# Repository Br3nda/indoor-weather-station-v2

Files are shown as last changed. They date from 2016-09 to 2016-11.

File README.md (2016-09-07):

# indoor-weather-station-v2
Software for VCW indoor weatherstation

## Licensing

This software is GPL 3.0.

Included is driver software - HTS221 and LPS25 drivers, with their own copyrights
they have been released by their author, Amel Technology, under the LGPL2.1 license

	https://github.com/ameltech/sme-hts221-library
	https://github.com/ameltech/sme-lps25h-library

Our minor changes to these files are also released under LGPL2.1

---------------------------------------------------------------

## Data compression formats:

###humidity/temp compression - humidity is 7 bits 0-100, temp is 8 bits signed C
```
if bit 7 of byte 0 is 1 then bits 6:0 of byte0 is % humidity, byte1 is temp in C
if bit 7 of byte 0 is 0 then bits 6:4 are a signed diff of humidity from previous value, 3:0 are a signed diff of temp from previous value
if bits 7:4 of byte 0 are 1111 it is an escape (see below)
```
 
###pressure compression
```
if bit 0 of byte0 is set bits 6:0 are a signed delta of the pressure in kPa
if bit 1 of byte0 is set bits 6:0 of byte0 is MSB of pressure, byte 1 is LSB of pressure in kPa
if bits 7:4 of byte 0 are 1111 it is an escape (see below)
```

###escapes
```
1111 1111 - end of stream (unwritten FLASH)
1111 0000 - time signature
1111 0001 - time signature + change following samples to temp/humidity only (first following sample will be a full sample)
1111 0010 - time signature + change following samples to pressure only (first following sample will be a full sample)
1111 0011 - time signature + change following samples to temp/humidity followed by pressure (first following sample will be a full sample)
1111 0100 - followed by 2 bytes MSB LSB, sampling rate in seconds (default is 60 seconds, one sample per minute)
1111 0101 - followed by 0 terminated string comment
1111 0110 - followed by a 1-byte value - 'mark' a user inserted mark in the stream (for example "I turned on the heater here")
1111 0111 - null - ignored for padding
1111 1000 - followed by 1-byte count 1-255 - previous value didn't change to N samples
1111 1001 - 1110 undefined
```

###time signature:
```
byte0 - bits 7:0 years since 2000 0-254 - value '0xff' means no time is known (bytes1-4 are missing)
byte1 - bits 7:4 month 1-12,  bits 3:0 day MSB 1-31
byte2 - bit 7 day LSB 1-23, bits 6:2 hour 0-23 bits 1:0 minutes msb
byte3 - bits 7:4 minutes lsb 0-59, bits 3:0 - F means byte4 not included, otherwise undefined, set to 0
byte4 - bits 7:6 undefined set to 0, bits 5:0 seconds
```

---------------------------------------------------------------

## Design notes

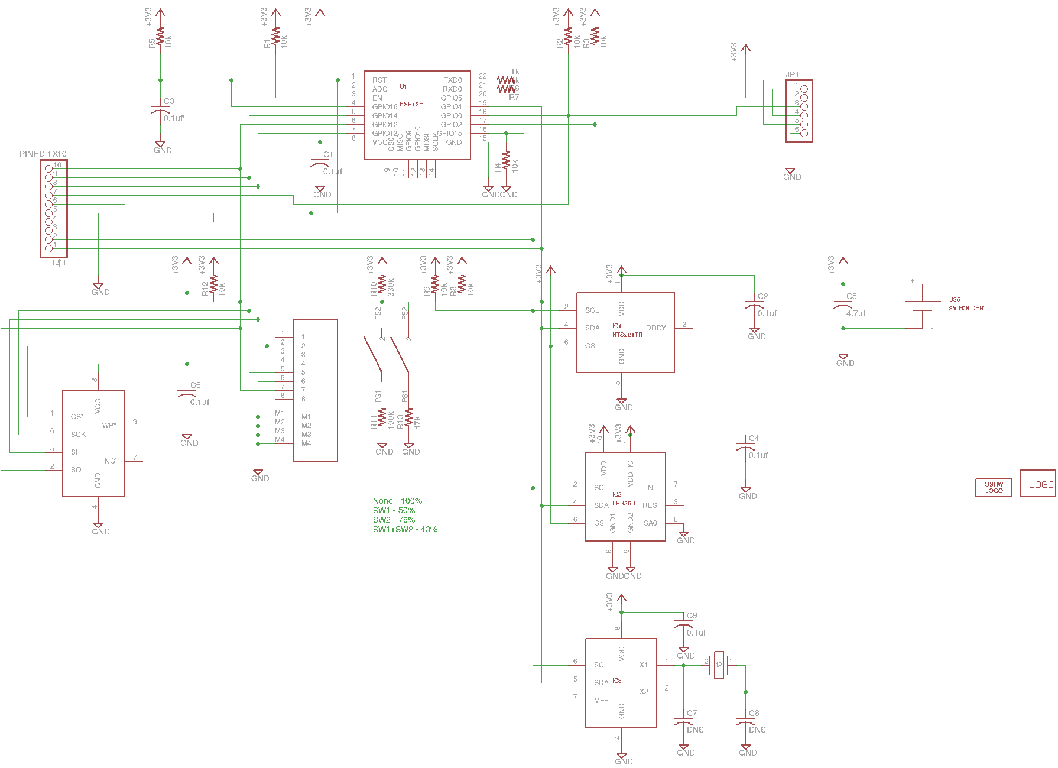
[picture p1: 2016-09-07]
hardware/housesensor.png

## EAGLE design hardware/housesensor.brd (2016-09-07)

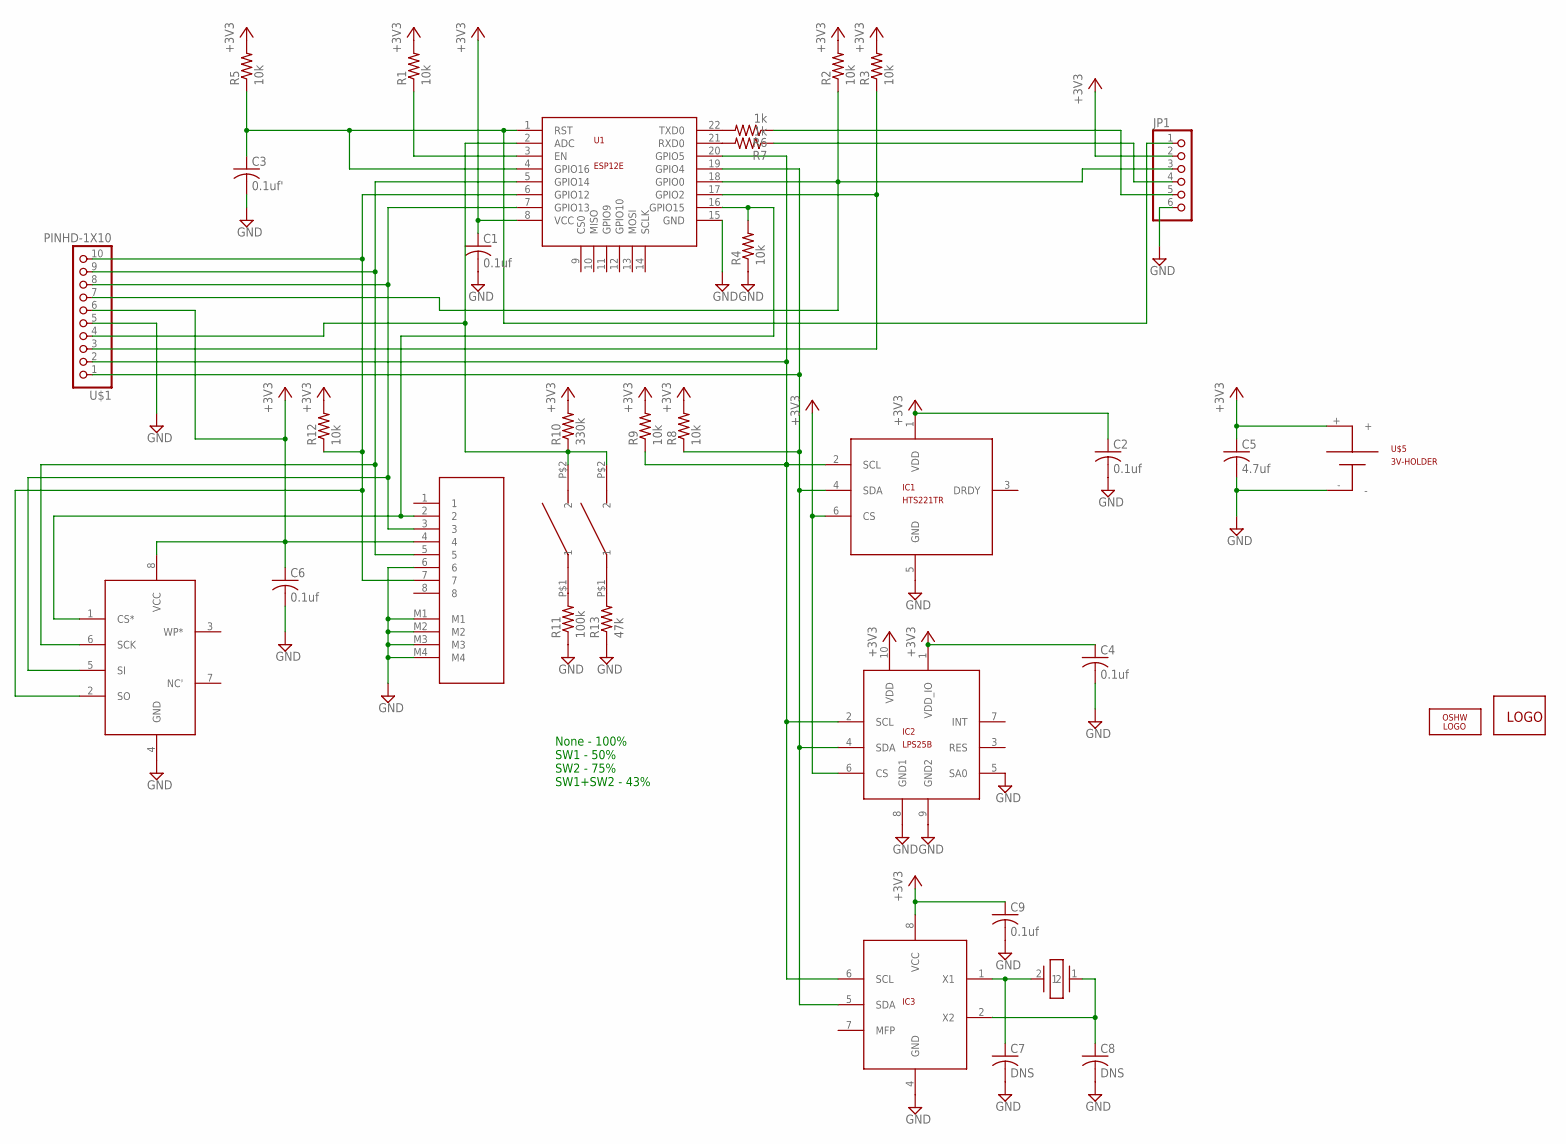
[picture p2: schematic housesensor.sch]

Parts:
C1, C2, C4, C6, C9: 0.1uf; C0603
C3: 0.1uf'; C0603
C5: 4.7uf; C1206
C7, C8: DNS; C0603
IC1: HTS221TR; HTS221
IC2: LPS25B; LPS25
IC3: MCP7940MS08M; SO8M
IC4: SPI-FLASH; SO8J
JP1: PINHD-1X6; 1X06
LOGO1: OSHW_LOGO_FILLX0150-NT; OSHW_FILLX150_NOTEXT
R1, R2, R3, R4, R5, R8, R9, R12: 10k; R0603
R6, R7: 1k; R0603
R10: 330k; R0603
R11: 100k; R0603
R13: 47k; R0603
SW1, SW2: RED-SWITCH; SW2
U1: ESP12E; ESP8266-SMD
U$1: PINHD-1X10; 1X10-BIG
U$4: MICRO-SD-SCHD1A0101; MICROSD-P
U$5: 3V-HOLDER
U$6: MOONBASE-LOGO
X1: 32KHZ

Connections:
+3V3: C1.1, C2.1, C4.1, C5.1, C6.1, C9.1, IC1.1 (VDD), IC1.6 (CS), IC2.1 (VDD_IO), IC2.6 (CS), IC2.10 (VDD), IC3.8 (VCC), IC4.8 (VCC), JP1.2, R1.2, R2.2, R3.2, R5.2, R8.2, R9.2, R10.2, R12.2, U1.8 (VCC), U$1.6, U$4.4, U$5.+
EN: R1.1, U1.3 (EN)
GND: C1.2, C2.2, C3.2, C4.2, C5.2, C6.2, C7.2, C8.2, C9.2, IC1.5 (GND), IC2.5 (SA0), IC2.8 (GND1), IC2.9 (GND2), IC3.4 (GND), IC4.4 (GND), JP1.6, R4.1, R11.1, R13.1, U1.15 (GND), U$1.5, U$4.6, U$4.M1, U$4.M2, U$4.M3, U$4.M4, U$5.-
GPIO0: JP1.3, R2.1, U1.18 (GPIO0), U$1.7
GPIO2: R3.1, U1.17 (GPIO2), U$1.3
GPIO12: IC4.2 (SO), R12.1, U1.6 (GPIO12), U$1.10, U$4.7
GPIO13: IC4.5 (SI), U1.7 (GPIO13), U$1.8, U$4.3
GPIO14: IC4.6 (SCK), U1.5 (GPIO14), U$1.9, U$4.5
GPIO15: IC4.1 (CS*), R4.2, U1.16 (GPIO15), U$4.2
unnamed: R11.2, SW1.P$1 (1)
unnamed: R10.1, SW1.P$2 (2), SW2.P$2 (2), U1.2 (ADC), U$1.4
unnamed: R13.2, SW2.P$1 (1)
unnamed: C8.1, IC3.2 (X2), X1.1
unnamed: C7.1, IC3.1 (X1), X1.2
unnamed: R6.2, U1.22 (TXD0)
unnamed: R7.2, U1.21 (RXD0)
unnamed: JP1.5, R6.1
unnamed: JP1.4, R7.1
RST: C3.1, JP1.1, R5.1, U1.1 (RST), U1.4 (GPIO16)
SCL: IC1.2 (SCL), IC2.2 (SCL), IC3.6 (SCL), R9.1, U1.20 (GPIO5), U$1.2
SDA: IC1.4 (SDA), IC2.4 (SDA), IC3.5 (SDA), R8.1, U1.19 (GPIO4), U$1.1

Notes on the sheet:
None - 100% SW1 - 50% SW2 - 75% SW1+SW2 - 43%

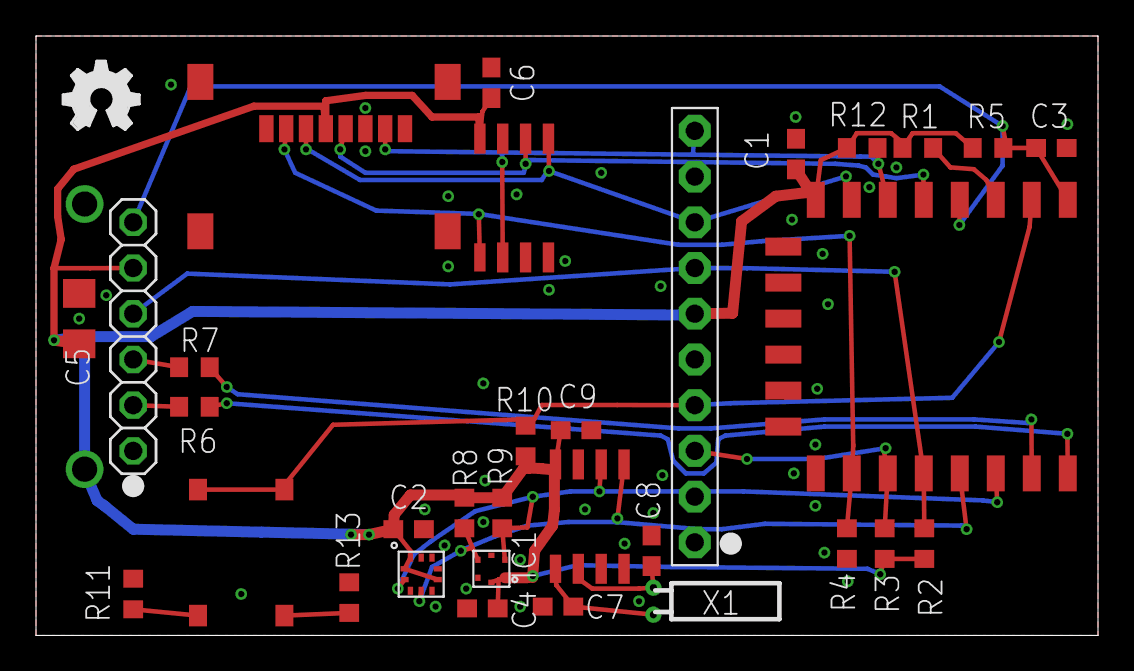
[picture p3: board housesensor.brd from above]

Board: 2 copper layers, 59.0 x 33.3 mm, 36 parts (1 on the bottom side), 21 nets.

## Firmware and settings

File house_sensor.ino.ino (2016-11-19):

/*   
 *   Copyright (C) 2016 Paul Campbell

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
 *   You should have received a copy of the GNU General Public License
 *   along with this program.  If not, see <http://www.gnu.org/licenses/>.
 */

      // humidity/temp compression - humidity is 7 bits 0-100, temp is 8 bits signed C
      // If bit 7 of byte 0 is 1 then bits 6:0 of byte0 is % humidity, byte1 is temp in C
      // if bit 7 of byte 0 is 0 then bits 6:4 are a signed diff of humidity from previous value, 2:0 are a signed diff of temp from previous value, bit 3 
      //      says that a following pressure value is unchanged and omitted
      // if bits 7:4 of byte 0 are 1111 it is an escape (see below)
      // 
      // pressure compression
      // if bit 0 of byte0 is set bits 6:0 are a signed delta of the pressure in kPa
      // if bit 1 of byte0 is set bits 6:0 of byte0 is MSB of pressure, byte 1 is LSB of pressure in kPa
      // if bits 7:4 of byte 0 are 1111 it is an escape (see below)
      //
      // escapes
      //  1111 1111 - end of stream (unwritten FLASH)
      //  1111 0000 - time signature
      //  1111 0001 - time signature + change following samples to temp/humidity only (first following sample will be a full sample)
      //  1111 0010 - time signature + change following samples to pressure only (first Afollowing sample will be a full sample)
      //  1111 0011 - time signature + change following samples to temp/humidity followed by pressure (first following sample will be a full sample)
      //  1111 0100 - followed by 2 bytes MSB LSB, sampling rate in seconds (default is 60 seconds, one sample per minute)
      //  1111 0101 - followed by 0 terminated string comment
      //  1111 0110 - followed by a 1-byte value - 'mark' a user inserted mark in the stream (for example "I turned on the heater here")
      //  1111 0111 - null - ignored for padding
      //  1111 1000 - followed by 1-byte count 1-255 - previous value didn't change to N samples
      //  1111 1001-1110 undefined
      //
      // time signature:
      //  byte0 - bits 7:0 years since 2000 0-254 - value '0xff' means no time is known (bytes1-4 are missing)
      //  byte1 - bits 7:4 month 1-12,  bits 3:0 day MSB 1-31
      //  byte2 - bit 7 day LSB 1-23, bits 6:2 hour 0-23 bits 1:0 minutes msb
      //  byte3 - bits 7:4 minutes lsb 0-59, bits 3:0 - F means byte4 not included, otherwise undefined, set to 0
      //  byte4 - bits 7:6 undefined set to 0, bits 5:0 seconds

#define COUNT 60            // how many samples before trying to push upstream
#define DELAY 1000000       // 1 SEC in uS
#define MAGIC 0x76          // increment this (mod 256) when you make changes to force initialisation
#define FLASH_ERASE 0

extern "C" {
  #include "user_interface.h"
  extern struct rst_info resetInfo; 
  void esp_yield();
}

#include "Wire.h"
#include "HTS221.h"
#include "LPS25H.h"
#include "PC8563.h"
#include "CaptiveConfig.h"
#include "DataUploader.h"
#include "decompress.h"
#include "house_eeprom.h"
#include "Flash.h"



#ifndef cbi
#define cbi(sfr, bit) (_SFR_BYTE(sfr) &= ~_BV(bit))
#endif

#ifndef sbi
#define sbi(sfr, bit) (_SFR_BYTE(sfr) |= _BV(bit))
#endif

#include "pins_arduino.h"
#include "twi.h"


typedef struct rtc_info {
    unsigned char magic;    // MAGIC number
    unsigned char count;    // how many times to wait
    unsigned char state;    
#define STATE_HUMID_PRESENT     0x01    // we have a humididty sensor
#define STATE_PRESSURE_PRESENT  0x02    // we have a pressure sensor
#define STATE_RTC_PRESENT       0x04    // we have an external RTC
#define STATE_SENSORS_ACTIVE    0x08    // take a sample when you wake up
#define STATE_TIME_SET          0x10    // RTC time is valid

    unsigned char   compressor_state;   //
#define CSTATE_SAME       0x01          // we have an active 'same' entry
#define CSTATE_LAST_SAME  0x02          // the last entry we put was deltas '0'
#define CSTATE_NOPR       0x04          // the last entry had a skipped - 0 pressure valoue
    unsigned long   delay;    // how long to wait for 
    unsigned short  last_pressure;      // 0xffff means no last value
    signed char     last_temp;          // 0x7f means no last value
    unsigned char   last_humidity;      // 0xff means no last value
    unsigned char   _h0_rH, _h1_rH;     // humidity calibration parameters
    signed short    _H0_T0, _H1_T0;
    unsigned short  _T0_degC, _T1_degC; // temp calibration parameters
    signed short    _T0_OUT, _T1_OUT;
    unsigned short  flash_start_offset; // offset of firest entry in flash

    unsigned char   boff; // offset into buffer for next sample
} rtc_info;

rtc_info save_info;
bool commit_rtc_data_pending=0;
void write_time_signature();
  
#define RTC_BUFF_BASE (sizeof(rtc_info))
#define RTC_BUFF_SIZE 255

#define HTS221_ADDRESS     0x5F
#define LPS25H_ADDRESS     0x5C

/// A CaptiveConfig is allocated in setup() if we want a config access point.
CaptiveConfig *configGetter(nullptr);

/// Similarly, DataUploader is used for uploading data over WiFi
DataUploader *dataUploader(nullptr);

// Needs to be at least 256 bytes to take a full record from HomeFlash
#define UPLOAD_BUFFER_SIZE 8 * 256

/// For passing data between flash and the DataUploader instance
uint8_t *uploadBuf(nullptr);

/// Used to confirm that device knows user wants to do something
uint8_t blinkCount(0);

/// Blinking is handled in loop(), undone by enter_deep_sleep()
void startBlink()
{
    pinMode(2, OUTPUT);
    blinkCount = 0x80;
}

// Unsure why, but Arduino precompiler thingy wants to put enter_deep_sleep()
// before rtc_mem_write...
void rtc_mem_write(int offset, void *p,  int bytes);

/// Call this, then return from setup() or loop() to enter deep sleep
void enter_deep_sleep()
{
  // Ensure that the notification LED is off before we go to sleep
  blinkCount = 0;
  digitalWrite(2, 1);
  eeprom.flush();

  save_info.flash_start_offset = flash.GetRememberedOffset();
  rtc_mem_write(0, &save_info, sizeof(save_info));
  system_deep_sleep_set_option(0);
  system_deep_sleep(save_info.delay);
  esp_yield();
}

void
rtc_mem_write(int offset, void *p,  int bytes)
{
  union {
      unsigned char b[4];
      unsigned long l;
  }b;
  unsigned char *pp = (unsigned char *)p;
  volatile uint32 *rtc = ((uint32*)0x60001100) + 64 + (offset>>2);

  offset &= 3;
  if (offset) {
    b.l = *rtc;

    for (int i = offset; i < 4 && bytes>0; i++) {
        b.b[i] = *pp++;
        bytes--;
    }
    *rtc++ = b.l;
    if (bytes == 0)
      return;
  }
  if (((int)pp)&3) {
    while (bytes >= 4) {
      b.b[0] = pp[0];
      b.b[1] = pp[1];
      b.b[2] = pp[2];
      b.b[3] = pp[3];
      *rtc++ = b.l;
      pp += 4;
      bytes -= 4;
    }
  } else {
    while (bytes >= 4) {
      *rtc++ = *(unsigned long *)pp;
      pp += 4;
      bytes -= 4;
    }
  }
  if (bytes&3) {
    b.l = *rtc;
    for (int i = 0; i < (bytes&3); i++)
      b.b[i] = *pp++;
    *rtc = b.l;
  }
}


void
rtc_mem_read(int offset, void *p,  int bytes)
{
  union {
      unsigned char b[4];
      unsigned long l;
  }b;
  unsigned char *pp = (unsigned char *)p;
  volatile uint32 *rtc = ((uint32*)0x60001100) + 64 + (offset>>2);

  offset &= 3;
  if (offset) {
    b.l = *rtc;
    for (int i = offset; i < 4 && bytes>0; i++) {
        *pp++ = b.b[i];
        bytes--;
    }
    if (bytes == 0)
      return;
    rtc++;
  }
  
  if (((int)pp)&3) {
    while (bytes >= 4) {
      b.l = *rtc++;
      pp[0] = b.b[0];
      pp[1] = b.b[1];
      pp[2] = b.b[2];
      pp[3] = b.b[3];  
      pp += 4;
      bytes -= 4;
    }
  } else {
    while (bytes >= 4) {
      *(unsigned long *)pp = *rtc++;
      pp += 4;
      bytes -= 4;
    }
  }
  if (bytes&3) {
    b.l = *rtc;
    for (int i = 0; i < (bytes&3); i++)
      *pp++ = b.b[i];
  }
}

unsigned char 
readRegister(unsigned char addr, unsigned char reg)
{
    Wire.beginTransmission(addr);
    Wire.write(reg);
    Wire.endTransmission(false);
    Wire.requestFrom((uint8_t)addr, (uint8_t)1);
    while(!Wire.available());
    return Wire.read();  
}

void
log_string(const char *s)
{
  unsigned char c = 0xf5; 
  save_info.compressor_state = 0;
  rtc_mem_write(RTC_BUFF_BASE+save_info.boff++, &c, 1);
  for (;;) {
    rtc_mem_write(RTC_BUFF_BASE+save_info.boff++, (unsigned char *)s, 1);
    if (!*s)
      break;
    s++;
  }
}
void 
writeRegister(unsigned char addr, unsigned char reg, unsigned char val)
{
    Wire.beginTransmission(addr);
    if (!Wire.write(reg))
        return;
    if (!Wire.write(val)) 
        return;
    Wire.endTransmission();
}


void 
unload_rtc_buffer(int sz)
{
    unsigned char b[255];
    
    int samples = dump_rtc_data();
    Serial.print(samples);
    Serial.print(" samples in ");
    Serial.print(save_info.boff);
    Serial.println("bytes");

    rtc_mem_read(RTC_BUFF_BASE, &b[0], sz);
    if (flash.WriteRecord(&b[0], sz)) {
      save_info.last_humidity = 255;
      save_info.last_temp = 127;
      save_info.last_pressure = 0;
      save_info.compressor_state &= ~(CSTATE_SAME|CSTATE_LAST_SAME|CSTATE_NOPR);
      save_info.boff = 0;
      write_time_signature();
    }
    printf("Dump flash\n");
    flash.Dump();
}

//
//  Call this routine to get at most max_len bytes of data into a buffer to send upstream
//  It returns 0 when no data is available otherwise the number of bytes extracted
//
//  If we return other than 0 then before we return to deep sleep, or before we call 
//  get_stored_flash_data() again, we must call one of:
//
//  commit_stored_flash_data() - makes the space sent upstream available for more storage
//  uncommit_stored_flash_data() - upstream write failed, leave the data in the flash for later
//  

int 
get_stored_flash_data(unsigned char *p, int max_len)
{
  unsigned long l = flash.LoadBuffer(p, max_len);

  commit_rtc_data_pending = 0;
  if (l&FLASH_END_MARKER) {
      l &= ~FLASH_END_MARKER;
      if (save_info.boff < (max_len-l)) {
        rtc_mem_read(RTC_BUFF_BASE, &p[l], save_info.boff);
        l += save_info.boff;
        commit_rtc_data_pending = 1;
      }
  }
  return l;
}

void
commit_stored_flash_data(void)
{
    flash.CommitBuffer();
    if (commit_rtc_data_pending) {
      save_info.last_humidity = 255;
      save_info.last_temp = 127;
      save_info.last_pressure = 0;
      save_info.compressor_state &= ~(CSTATE_SAME|CSTATE_LAST_SAME|CSTATE_NOPR);
      save_info.boff = 0;
    }
}

void
uncommit_stored_flash_data(void)
{
  flash.UnCommitBuffer();
  commit_rtc_data_pending = 0;
}

void
write_time_signature()
{
    unsigned char b[6];

    save_info.compressor_state = 0;
    if (save_info.boff > (RTC_BUFF_SIZE-6-(save_info.delay==60000000?0:3))) {  // room for another?
      unload_rtc_buffer(save_info.boff);
      return; // unloads as a side effect
    } 
    b[0] = 0xf0 | (save_info.state&STATE_HUMID_PRESENT?1:0) | (save_info.state&STATE_PRESSURE_PRESENT?2:0);
    if ((save_info.state&(STATE_RTC_PRESENT|STATE_TIME_SET)) == (STATE_RTC_PRESENT|STATE_TIME_SET)) {
      pc_time tm;

      memset(&tm, 0, sizeof(tm));
      PC8563_RTC.read(tm);
      b[1] = tm.year-2000;
      b[2] = (tm.month<<4) | (tm.day>>1);
      b[3] = (tm.day<<7) | (tm.hour<<2) | (tm.minute>>4);
      b[4] = (tm.minute<<4) | 0xf;
      rtc_mem_write(RTC_BUFF_BASE+save_info.boff, &b[0], 5); // save the data
      save_info.boff += 5;
    } else {
      b[1] = 0xff;
      rtc_mem_write(RTC_BUFF_BASE+save_info.boff, &b[0], 2); // save the data
      save_info.boff += 2;
    }
    if (DELAY!=60000000) { // not 1 minute? output sampling rate
      int v = DELAY/1000000;
      b[0] = 0xf4;
      b[1] = v>>8;
      b[2] = v;
      rtc_mem_write(RTC_BUFF_BASE+save_info.boff, &b[0], 3); // save the data
      save_info.boff += 3;
    }
    if (save_info.boff > (RTC_BUFF_SIZE-4))   // room for another?
      unload_rtc_buffer(save_info.boff);
}

int 
get_compressed_byte(int offset) // called when dumping rtc contents
{
  unsigned char c;
  
  if (offset >= save_info.boff)
    return -1;
  rtc_mem_read(RTC_BUFF_BASE+offset, &c, 1);
  return c;
}

bool
XinitVariant() 
{
  // WARNING - crappy stack hacking occurs at the end of this routine if you add
  //    varibles here you must update the asm at the end of this routine
  //    
  unsigned long tm;
  unsigned char th_delta;
  unsigned char p_delta;
  signed char temp;
  unsigned char humidity;
  unsigned char status;
  bool force;
  bool same;
  int v;
  int dt, dh;
  int sz;
  unsigned char b[4];
  unsigned short adc;
 // end WARNING
 
 if (resetInfo.reason != REASON_DEEP_SLEEP_AWAKE)  // power on go set stuff up
    return 0;

  // ADC:
  //    1024 - nothing pressed
  //    369   - top button pressed    - upload data
  //    677   - bottom button pressed - insert mark in data
  //    265   - both buttons pressed  - go into setup mode
  //    
 adc = system_adc_read();
 
// Serial.print("adc=");  
// Serial.println(adc);

  rtc_mem_read(0, &save_info, sizeof(save_info));  
//  Serial.println("");  
//  Serial.print("state=");  
//  Serial.println(save_info.state,HEX);
  if (save_info.magic != MAGIC)
    return 0;
  flash.SetRememberedOffset(save_info.flash_start_offset);
  if (save_info.state&STATE_SENSORS_ACTIVE) {
    if (adc > 500 && adc < 900) { // insert mark
      b[0] = 0xf6; // mark
      b[1] = 0x0;  // default mark
      rtc_mem_write(RTC_BUFF_BASE+save_info.boff, &b[0], 2); // save the data
      save_info.boff += 2;
      if (save_info.boff > (RTC_BUFF_SIZE-4)) {  // room for another?
       unload_rtc_buffer(save_info.boff);
      }
    }
    force=0;
    same=0;
    // activate internal pullups for twi.
    Wire.begin(4, 5);
    
    if (save_info.state&STATE_HUMID_PRESENT) 
      writeRegister(HTS221_ADDRESS, 0x20, 0x80|3); // wake up the HTS221
    if (save_info.state&STATE_PRESSURE_PRESENT) 
      writeRegister(LPS25H_ADDRESS, 0x20, 0x80|0x40); // wake up the LP25
    if (save_info.state&STATE_HUMID_PRESENT) {
      for (;;) {
        status = readRegister(HTS221_ADDRESS, 0x27);
        if (status&0x02) // humidity ready
            break;
      }
      v = readRegister(HTS221_ADDRESS, 0x29)<<8;
      v |= readRegister(HTS221_ADDRESS, 0x28);
//Serial.print("v=");
//Serial.println(v);
      if (v&0x8000)
        v |= 0xffff0000;

      v = (save_info._h0_rH + (((v-save_info._H0_T0)*(save_info._h1_rH-save_info._h0_rH))/(save_info._H1_T0-save_info._H0_T0)))>>1;
      if (v < 0) v = 0; else
      if (v > 100) v = 100;
      humidity = v;
//Serial.print("humidity=");Serial.println(humidity);
      for (;;) {
        if (status&0x01) // temp ready
            break;
        status = readRegister(HTS221_ADDRESS, 0x27);
      }
      v = readRegister(HTS221_ADDRESS, 0x2b)<<8;
      v |= readRegister(HTS221_ADDRESS, 0x2a);
      writeRegister(HTS221_ADDRESS, 0x20, 0);
//printf("in %d %d\n", save_info._T0_degC, save_info._T1_degC);
//printf("out %d %d\n", save_info._T0_OUT,save_info._T1_OUT);
//printf("cvt %d ", v);
      v = ((save_info._T0_degC + (((int16_t)v-(int16_t)save_info._T0_OUT)*(save_info._T1_degC-save_info._T0_degC))/((int16_t)save_info._T1_OUT-(int16_t)save_info._T0_OUT))+3)>>3;
      temp = v;
//printf("%d\n", v);
//Serial.print("temp=");Serial.println(temp);
      dt = temp-save_info.last_temp;
      save_info.last_temp = temp;
      dh = humidity-save_info.last_humidity;
      save_info.last_humidity = humidity;
      if (dh > 3 || dh < -4 || dt > 3 || dt < -4)
          force = 1;
//Serial.print("dh=");Serial.println(dh);
//Serial.print("dt=");Serial.println(dt);
      th_delta = (dt&0x7)|((dh&0x7)<<4);
    } else {
      th_delta = 0x00;
    }
    if (save_info.state&STATE_PRESSURE_PRESENT) {
      while (!(readRegister(LPS25H_ADDRESS, 0x27)&0x02))
        ;             
      v = readRegister(LPS25H_ADDRESS, 0x2a)<<4;  // MSB
      v |=  readRegister(LPS25H_ADDRESS, 0x29)>>4; //LSB
      writeRegister(LPS25H_ADDRESS, 0x20, 0x10);
      dt = v-save_info.last_pressure;
//Serial.print("press=");
//Serial.println(v);
      save_info.last_pressure = v;
      if (dt > 63 || dt < -64)
        force = 1;
// Serial.print("dt=");
//Serial.println(dt&0xff,HEX);
      p_delta = (dt&0x7f);
    } else {
      p_delta = 0;
    }
    sz=0;
//Serial.print(th_delta,HEX);
// Serial.print("--");
//Serial.println(p_delta,HEX);
    if (force) {    // force means send full values rather than del;tas
      save_info.compressor_state &= ~(CSTATE_SAME|CSTATE_LAST_SAME|CSTATE_NOPR);
      if (save_info.state&STATE_HUMID_PRESENT) {
        b[0] = 0x80|save_info.last_humidity;
        b[1] = (unsigned char)save_info.last_temp;
        sz = 2;
      } else {
        sz = 0;
      }
      if (save_info.state&STATE_PRESSURE_PRESENT) {
        b[sz] = 0x80|(save_info.last_pressure>>8);
        b[sz+1] = save_info.last_pressure;
        sz += 2;
      }
    } else {
      if (th_delta == 0x00 && p_delta == 0x00) {

// Serial.print("cstate=");
//Serial.println(save_info.compressor_state,HEX);        
         if (save_info.compressor_state&CSTATE_SAME) { // 3rd and subsequent deltas
            rtc_mem_read(RTC_BUFF_BASE+save_info.boff-1, &status, 1);
            if (status == 255) {   // repeat is full, add an extra one
                sz = 2;
                b[0] = 0xf8;
                b[1] = 1;
            } else {          // increment count
                save_info.boff--;
                b[0] = status+1;
                sz = 1;
            }
        } else
        if (save_info.compressor_state&CSTATE_LAST_SAME) { // 2nd delta convert previous delta into a 'repeat'
            if (save_info.state&STATE_HUMID_PRESENT) 
              save_info.boff--;
            if (save_info.state&STATE_PRESSURE_PRESENT && !(save_info.compressor_state&CSTATE_NOPR)) 
              save_info.boff--;
            save_info.compressor_state &= ~(CSTATE_LAST_SAME|CSTATE_NOPR);
            save_info.compressor_state |= CSTATE_SAME;
            sz = 2;
            b[0] = 0xf8;
            b[1] = 2;
        } else { // first '0' delta just store the '0'
          save_info.compressor_state |= CSTATE_LAST_SAME;          
          sz = 0;
          if (save_info.state&STATE_HUMID_PRESENT) {
            b[sz++] = th_delta|0x08;
            save_info.compressor_state |= CSTATE_NOPR;
          } else
          if (save_info.state&STATE_PRESSURE_PRESENT)
            b[sz++] = p_delta;
        }
      } else {  // non-0 delta just save the deltas
        save_info.compressor_state &= ~(CSTATE_SAME|CSTATE_LAST_SAME);
        sz = 0;
        if (p_delta == 0x00 && (save_info.state&(STATE_HUMID_PRESENT|STATE_PRESSURE_PRESENT)) == (STATE_HUMID_PRESENT|STATE_PRESSURE_PRESENT)) {
          save_info.compressor_state |= CSTATE_NOPR;
          b[sz++] = th_delta|0x08; 
        } else {
          save_info.compressor_state &= ~CSTATE_NOPR;
          if (save_info.state&STATE_HUMID_PRESENT)
            b[sz++] = th_delta;
          if (save_info.state&STATE_PRESSURE_PRESENT)
            b[sz++] = p_delta;
        }
      }
    }

    rtc_mem_write(RTC_BUFF_BASE+save_info.boff, &b[0], sz); // save the data
    save_info.boff += sz;
    if (save_info.boff > (RTC_BUFF_SIZE-4)) {  // room for another?
      unload_rtc_buffer(save_info.boff);
    }
  }
//printf("off=%d\n", save_info.boff);
  save_info.count--;
  save_info.flash_start_offset = flash.GetRememberedOffset(); // save offset
  rtc_mem_write(0, &save_info, sizeof(save_info));
  if (!save_info.count)
      return 0;
  // ADC:
  //    1024 - nothing pressed
  //    369   - top button pressed    - upload data
  //    677   - bottom button pressed - insert mark in data
  //    265   - both buttons pressed  - go into setup mode
  //    
  if (adc < 500)  // if 'upload data' or 'go into setup mode' got into setup
    return 0;
  system_deep_sleep_set_option(0);
  system_deep_sleep(save_info.delay);
return 1;
  // unwind this stack frame and fake a return from user_init
  asm("l32i.n a0,a1,12+16;addi a1,a1,16+16;ret.n"); 
  // change '64' to match how much space gets allocated for this routine - '16' for the stack frame  
  // to find out the value run objdump on the resulting elf file, find the second line of initVariant()
  // it will be something like "addi    a1, a1, -48" take the '48' or whatever from here and replace it in the asm above (twice)
}
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
void 
loop() {
    if(blinkCount) {
        digitalWrite(2, !(--blinkCount & 0x10) );
    }

    // Note that we shouldn't have both a configGetter and
    // a dataUploader active at the same time.
    if( configGetter ) {
        if( configGetter->haveConfig() ) {
            Serial.println("Got config");

            auto ep(eeprom.get_pointer());
            auto config(configGetter->getCredentials());

            strncpy(ep->wifiSsid, config.ssid.c_str(), sizeof(ep->wifiSsid));
            ep->wifiSsid[ sizeof(ep->wifiSsid) - 1 ] = '\0';

            strncpy(ep->wifiPass, config.passphrase.c_str(), sizeof(ep->wifiPass));
            ep->wifiPass[ sizeof(ep->wifiPass) - 1 ] = '\0';

            eeprom.changed();

            Serial.println("Registration Email:");
            Serial.println(configGetter->getEmail());

            delete configGetter;
            configGetter = nullptr;
            enter_deep_sleep();
            return;
        }
        delay(15);
    } else if( dataUploader ) {
        if( dataUploader->isDone() ) {
            Serial.print("Uploader done...");

            if( dataUploader->succeeded() ) {
                commit_stored_flash_data();
                Serial.println("Success!");
            } else {
                uncommit_stored_flash_data();
                Serial.println("Failed!");
            }

            delete dataUploader;
            dataUploader = nullptr;

            delete [] uploadBuf;

            enter_deep_sleep();
            return;
         }
        // Note timeouts in DataUploader depend on this value
        delay(15);
    }
}

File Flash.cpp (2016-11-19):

/*   
 *   Copyright (C) 2016 Paul Campbell

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
 *   You should have received a copy of the GNU General Public License
 *   along with this program.  If not, see <http://www.gnu.org/licenses/>.
 */
#include "Arduino.h"

extern "C" {
#include "c_types.h"
#include "ets_sys.h"
#include "os_type.h"
#include "osapi.h"
#include "spi_flash.h"
}
#include "Flash.h"


//
//  we have N pages of SPI_FLASH_SEC_SIZE bytes
//
//  each page starts with a 4 byte magic number followed by a 4 byte ref number - FFFFFFFF means empty, 
//  every time we allocate a page we give it an increasing ref number, they are allocated in order going 
//  backwards (so we can grow the code), they wrap, then overflow to external flash where the same thing 
//  happens (not yet implemented)
//
//  we can find the first record simply by searching thru the pages
//
//  8266 flash operations must be 4 byte aligned, and a multiple of 4 bytes.
//
//  within each page there are a bunch of 'records', each is self contained (in the sense that compression 
//  restarts on each), they start with a length byte followed by data (max 255 bytes) the length 
//  is the actual length of the embedded data -1 (so values 0-254 representing 1-255, a value of 
//  255 is the last as yet unused record), records are 4 byte aligned and padded out to 4 byte boundaries
//


#define SEC_MAX_DATA (SPI_FLASH_SEC_SIZE-sizeof(flash_page_header))



HomeFlash flash;

void
HomeFlash::DoInit()
{
  flash_page_header h;
  unsigned int last_ref;
printf("doinit\n");
  current_page_address = first_page_address = (FLASH_LAST*SPI_FLASH_SEC_SIZE);
  spi_flash_read(current_page_address, (unsigned int *)&h, sizeof(h));
  last_ref = h.ref;
  if (h.magic == FLASH_MAGIC && h.ref != 0xffffffff) {
printf("doinit 1\n");
    unsigned int  address = (FLASH_FIRST*SPI_FLASH_SEC_SIZE);
    int last_page_address = current_page_address;
    spi_flash_read(address, (unsigned int *)&h, sizeof(h));
    while (h.magic == FLASH_MAGIC && h.ref == (last_ref-1)) {
        last_ref = h.ref;
        last_page_address = address;
        address += SPI_FLASH_SEC_SIZE;
        spi_flash_read(address, (unsigned int *)&h, sizeof(h));
    }
    first_page_address = last_page_address;
  } else {
printf("doinit 2\n");
    for (int i = 0; i < (FLASH_LAST-FLASH_FIRST+1); i++) {
      spi_flash_read(current_page_address, (unsigned int *)&h, sizeof(h));
      if (h.magic == FLASH_MAGIC && h.ref != 0xffffffff) 
        break;
      current_page_address -= SPI_FLASH_SEC_SIZE;
    }
    if (current_page_address < (FLASH_FIRST*SPI_FLASH_SEC_SIZE)) {  // empty - make an initial empty record
printf("doinit - empty\n");
      current_page_address = first_page_address = (FLASH_LAST*SPI_FLASH_SEC_SIZE);
      
      EraseSector(current_page_address/SPI_FLASH_SEC_SIZE);
      
      h.magic = FLASH_MAGIC;
      h.ref = 0;
      next_ref = 1;
printf("doinit - writing data 0x%x\n", current_page_address);
      noInterrupts();
      if (spi_flash_write(current_page_address, reinterpret_cast<uint32_t*>(&h), sizeof(h)) != SPI_FLASH_RESULT_OK) {
        interrupts();
printf("doinit - writing data retry 0x%x\n", current_page_address);
        noInterrupts(); // retry
        spi_flash_write(current_page_address, reinterpret_cast<uint32_t*>(&h), sizeof(h));
      }
      interrupts();
      first_page_offset = current_page_offset = 0;
      goto done;
    }
    first_page_address = current_page_address;
  }
printf("doinit a fpa=0x%x cpa = 0x%x\n", first_page_address, current_page_address);
  for (;;) {
      unsigned int address = current_page_address-SPI_FLASH_SEC_SIZE;
      if (address < (FLASH_FIRST*SPI_FLASH_SEC_SIZE))
        break;
      spi_flash_read(address, (unsigned int *)&h, sizeof(h));
      if (h.magic != FLASH_MAGIC || h.ref != (last_ref+1))
        break;
     current_page_address = address;
     last_ref = h.ref;
  }
printf("doinit b fpa=0x%x cpa = 0x%x\n", first_page_address, current_page_address);
  next_ref = h.ref+1;
  // now search for end of page
  current_page_offset = 0;
  for (;;) {
      unsigned char v;
      if (current_page_offset >= SEC_MAX_DATA)
        break;
      v = read_length(current_page_address+sizeof(flash_page_header)+current_page_offset);
      if (v == 0xff)
        break;
      current_page_offset += (v+2+3)&~3;
  }
done:
printf("doinit done\n");
  next_page_address = first_page_address;
  next_page_offset = first_page_offset;
  init = 1;
}

bool 
HomeFlash::WriteRecord(unsigned char *p, int len) // write a record len <= 255
{
  union {
      unsigned char b[256];
      unsigned int align;
  }b;

printf("write record %d bytes\n", len);
  if (len <= 0 || len > 255)
    return 0;
  if (!init)
    DoInit();
  int sz = (1+len+3)&~3;
  b.b[0] = len-1;
  memcpy(&b.b[1], p, len);
  for (int i = len+1; i < len; i++)
    b.b[i] = 0xff;
  if (full) {
    printf("data is full\n");
    return 0;
  }
  if ((current_page_offset+sz) > SEC_MAX_DATA) { // current page is full move to the next 
    unsigned int n;
    
    if (current_page_address == (FLASH_FIRST*SPI_FLASH_SEC_SIZE)) {
      n = FLASH_LAST*SPI_FLASH_SEC_SIZE;
    } else {
      n = current_page_address-SPI_FLASH_SEC_SIZE;
    }
    if (n == first_page_address) {
      full = 1;
      printf("data is full\n");
      // here's where we overflow into external flash
      return 0;
    } 
    current_page_address = n;
    EraseSector(current_page_address/SPI_FLASH_SEC_SIZE);
    flash_page_header h;
    h.magic = FLASH_MAGIC;
    h.ref = next_ref++;
printf("writing header 0x%x\n", current_page_address);
    noInterrupts();
    if (spi_flash_write(current_page_address, reinterpret_cast<uint32_t*>(&h), sizeof(h)) != SPI_FLASH_RESULT_OK) {
      interrupts();
      noInterrupts(); // retry
      if (spi_flash_write(current_page_address, reinterpret_cast<uint32_t*>(&h), sizeof(h))!= SPI_FLASH_RESULT_OK) {
        interrupts();
        return 0;
      }
    }
    interrupts();
    current_page_offset = 0;
  }
printf("writing %d bytes to 0x%x\n", sz, current_page_address+current_page_offset);
  noInterrupts();
  if (spi_flash_write(current_page_address+sizeof(flash_page_header)+current_page_offset, reinterpret_cast<uint32_t*>(&b.b[0]), sz) != SPI_FLASH_RESULT_OK) {
    interrupts();
    noInterrupts(); // retry
    if (spi_flash_write(current_page_address+sizeof(flash_page_header)+current_page_offset, reinterpret_cast<uint32_t*>(&b.b[0]), sz) != SPI_FLASH_RESULT_OK) {
      interrupts();
      return 0;
    }
  }
  interrupts();
  current_page_offset += sz;
  return 1;
}
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

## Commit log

2016-09-07 Add v1.0 hardware design files
    [housesensor.brd, housesensor.sch]
2016-09-15 Add basic support for buttons - mark stream
2016-09-15 Add sample code for Ian to fill in
2016-09-17 Blink LED when starting captive config.
2016-10-12 change compression to recognise that pressure doesn't change much
    [decompress.c, house_sensor.ino.ino]
2016-10-12 remove trace
2016-10-19 Handle missing WiFi network in DataUploader.
    [DataUploader.cpp]
2016-10-22 redesign eeprom to avoid using extra space and making extra copies
    [house_eeprom.cpp, house_sensor.ino.ino]
2016-10-22 More gracefully handle case where no APs are found
    Should also make sure the Captive Config UI looks OK.
2016-11-07 Fix copy-and-paste error. Was using SSID for pass.
    [house_sensor.ino.ino]
2016-11-19 Fix buffer overrun in HomeFlash::LoadBuffer()
    [Flash.cpp]
2016-11-19 Fix memory leak when uploading data.
    [house_sensor.ino.ino]

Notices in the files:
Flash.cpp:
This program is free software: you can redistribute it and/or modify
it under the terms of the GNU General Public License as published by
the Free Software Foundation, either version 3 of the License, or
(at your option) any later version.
